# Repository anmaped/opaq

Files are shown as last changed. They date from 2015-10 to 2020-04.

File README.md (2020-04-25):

# Opaq - IoT aquarium and pond controllers for everyone
#### Release 1.0.7



Main screen |  Settings Screen | Wifi Settings | Graph
:-----------:|:----------------:|:------:|:-------:
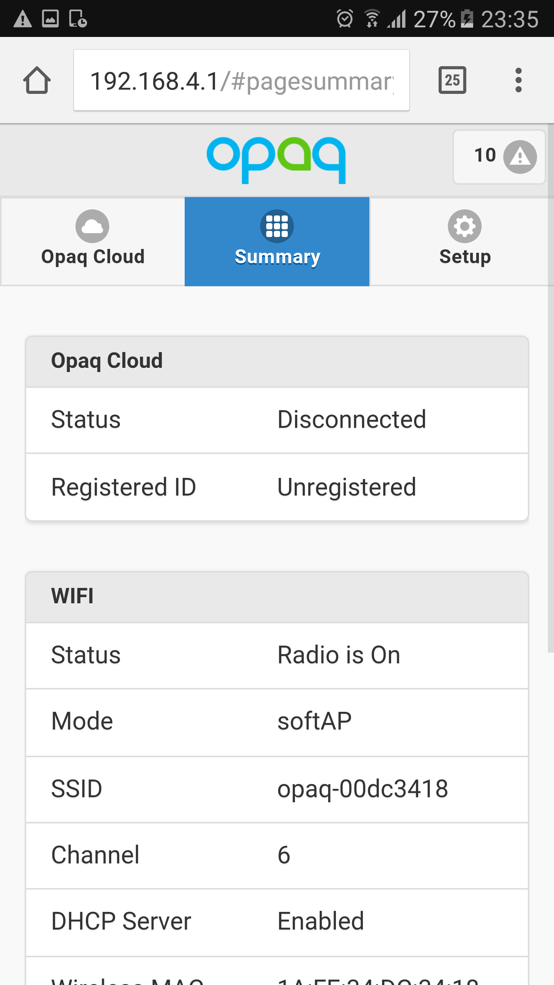
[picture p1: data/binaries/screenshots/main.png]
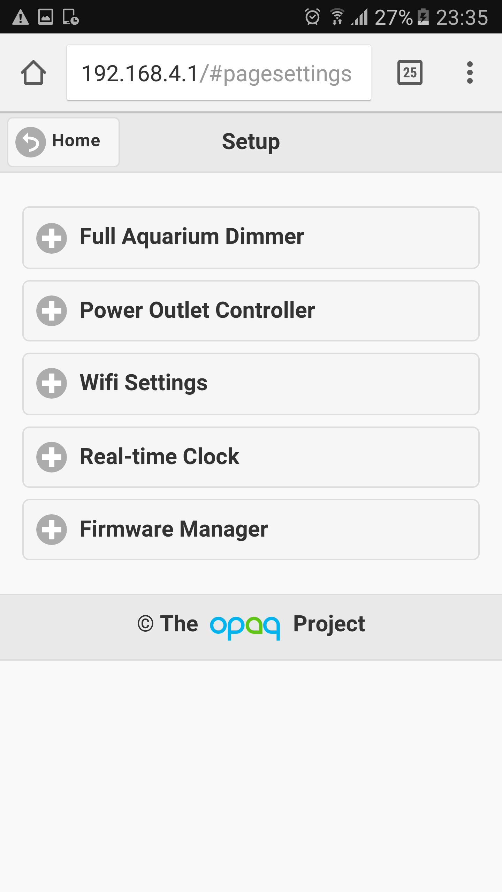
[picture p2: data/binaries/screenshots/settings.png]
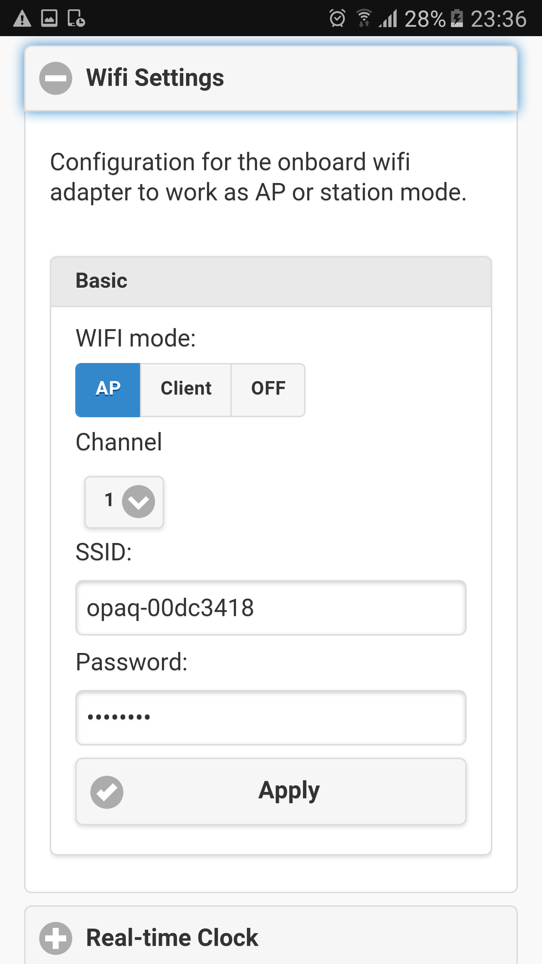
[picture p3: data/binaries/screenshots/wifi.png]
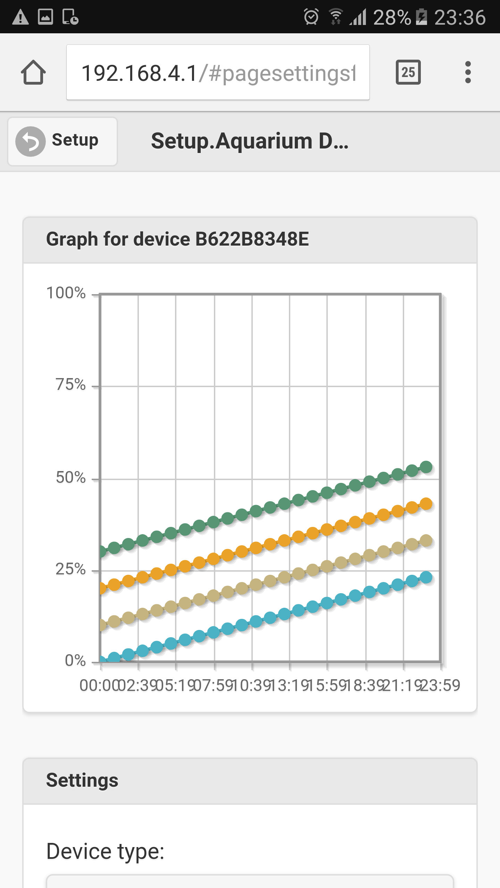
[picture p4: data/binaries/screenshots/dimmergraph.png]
 |   |   |  

Supported features:
- Browser-based graphical user interface to control light and power devices of aquarium and pond systems
- Customizable programming actions for nodes such as automation of CO2 injection and temperature management
- Node-based architecture (nodes are authentic, secured with SHA256 signatures)
- Energy cost management that instruct you how to avoid wasting energy

Opaq devices available:

Opaq c1 | Opaq n1 | Opaq n2 | Opaq n3
:------:|:---------:|:---------:|:---------:
the main controller device Opaq C1 Frame | the four channel dimmer device capable to connect with any led lamp (several settings available) Opaq n1 Frame | the power outlet controller node for 220v devices up to 1400w Opaq n2 Frame | battery powered wireless sensor node Opaq n3 Frame

Expected features:
- Support for sensor logging (temperature, humidity, light intensity, PH, Nitrates(NO3))
- Management of peristaltic pumps for automatic fertilization regimes for fresh and salt water aquariums
- Dedicated settings for aquarium and pond systems (pond systems can be controlled by Opaq C1 to automatically perform programmable water changes, and feed fishes; pumps are controlled by programmable actions based on the information provided by water level sensor nodes)
- Dedicated non-introsive water management system based on opaq n2 battery powered 'mope' for sumps and Koi ponds
- Embedded UI

Expected Hardware:
- Opaq N3 (the node for probing PH, light intensity and humidity)

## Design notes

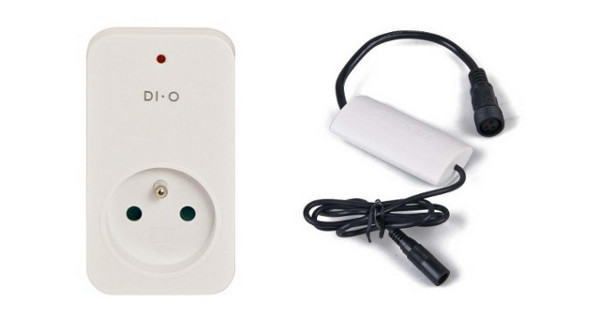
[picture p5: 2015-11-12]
tools/images/lp_sample.jpeg

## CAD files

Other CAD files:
hardware/opac_c1/v1.1/eagleUp/board.skp
hardware/opac_n1/v2.1/eagleUp/board.skp

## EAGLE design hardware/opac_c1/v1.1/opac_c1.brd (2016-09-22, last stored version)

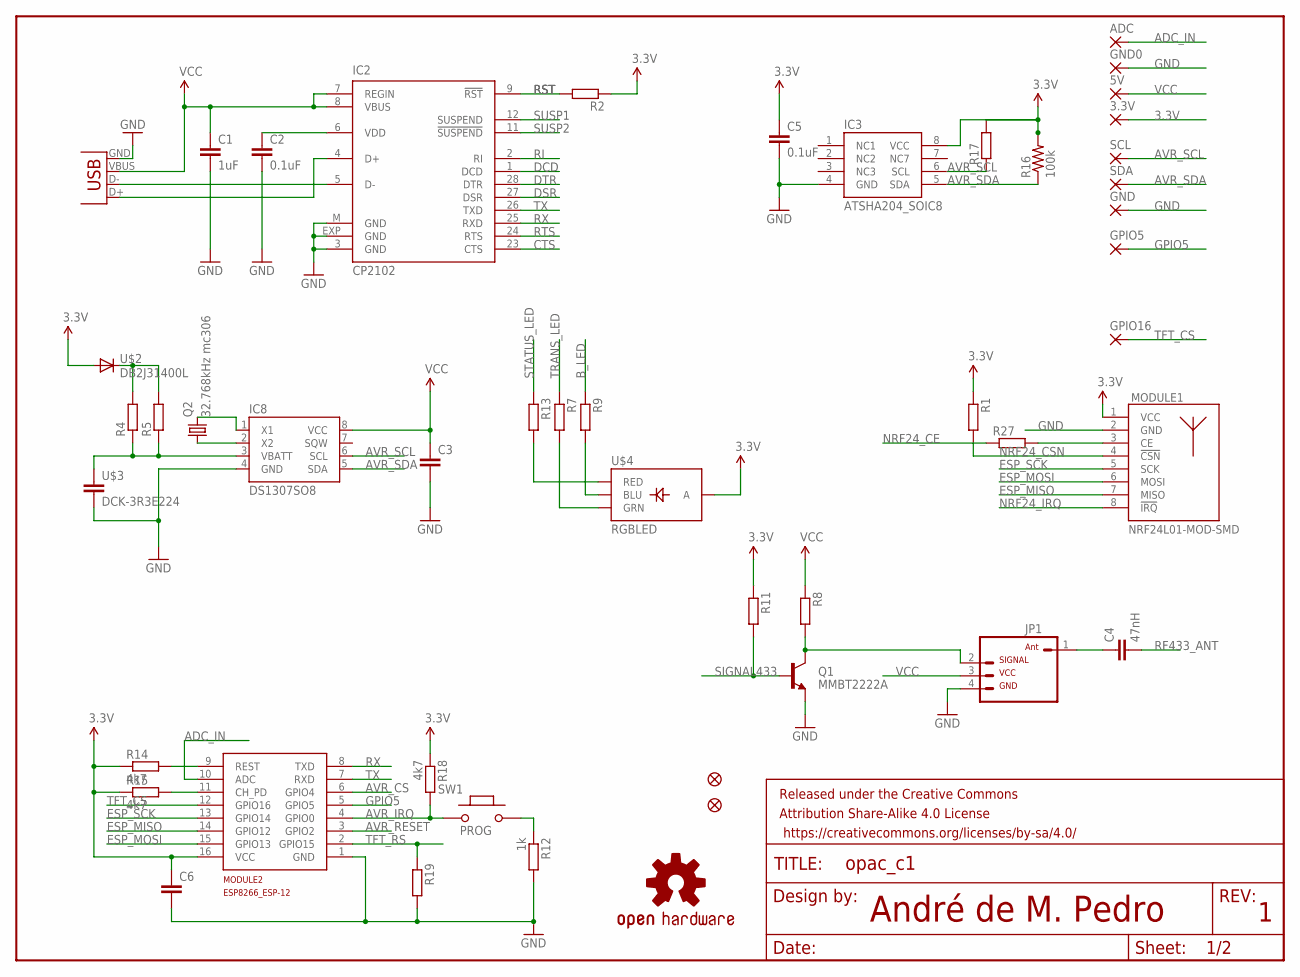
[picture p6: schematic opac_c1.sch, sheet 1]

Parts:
3.3V, 5V: SMD2; SMD1,27-2,54
ADC: SMD2; SMD1,27-2,54
C1: 1uF; 0603
C2: 0.1uF; 0603
C3, C6: C-EUC0805K; C0805K
C4: 47nH; C0603K
C5: 0.1uF; 0805
FRAME1: FRAME-LETTER; CREATIVE_COMMONS
GND, GND0: SMD2; SMD1,27-2,54
GPIO5, GPIO16: SMD2; SMD1,27-2,54
IC2: CP2102; MLP28
IC3: ATSHA204_SOIC8; SOIC8
IC8: DS1307SO8; SO08
JP1: RF433SMD; 1X04-SMD
JP2, JP3: FIDUCIAL1X2.5; FIDUCIAL-1X2.5
LOGO1: OSHW-LOGOL; OSHW-LOGO-L
MODULE1: NRF24L01-MOD-SMD; SMD8-MODULE
MODULE2: ESP8266_ESP-12; ESP8266-ESP12
Q1: MMBT2222A; SOT23-3
Q2: 32.768kHz mc306; MC-306
R1, R4, R5, R8, R11, R17, R19, R27: R-EU_R0805; 0805
R2, R7, R9, R13: R-EU_R0603; R0603
R12: 1k; 0805
R14, R15, R18: 4k7; 0805
R16: 100k; 0805
SCL: SMD2; SMD1,27-2,54
SDA: SMD2; SMD1,27-2,54
SW1: PROG; 157SW; PARTNO RS 682-1421
U$2: DB2J31400L; SMINI2-F5-B
U$3: DCK-3R3E224
U$4: RGBLED; RGBLED0603
USB1: USB-MICROB

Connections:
3.3V: 3.3V.1, C5.1, C6.1, IC3.8 (VCC), MODULE1.1 (VCC), MODULE2.16 (VCC), R1.1, R2.1, R11.1, R14.1, R15.1, R16.2, R17.2, R18.1, U$2.P$2 (A), U$4.P$3 (A); also elsewhere on the board
ADC_IN: ADC.1, MODULE2.10 (ADC)
AVR_CS: MODULE2.6 (GPIO4); also elsewhere on the board
AVR_IRQ: MODULE2.4 (GPIO0), R18.2, SW1.1; also elsewhere on the board
AVR_RESET: MODULE2.3 (GPIO2); also elsewhere on the board
AVR_SCL: IC3.6 (SCL), IC8.6 (SCL), R17.1, SCL.1; also elsewhere on the board
AVR_SDA: IC3.5 (SDA), IC8.5 (SDA), R16.1, SDA.1; also elsewhere on the board
B_LED: R9.1; also elsewhere on the board
CTS: IC2.23 (CTS)
DCD: IC2.1 (DCD)
DSR: IC2.27 (DSR)
DTR: IC2.28 (DTR)
ESP_MISO: MODULE1.7 (MISO), MODULE2.14 (GPIO12); also elsewhere on the board
ESP_MOSI: MODULE1.6 (MOSI), MODULE2.15 (GPIO13); also elsewhere on the board
ESP_SCK: MODULE1.5 (SCK), MODULE2.13 (GPIO14); also elsewhere on the board
GND: C1.2, C2.2, C3.2, C5.2, C6.2, GND.1, GND0.1, IC2.3 (GND), IC2.EXP (GND), IC2.M (GND), IC3.4 (GND), IC8.4 (GND), JP1.4 (2), MODULE1.2 (GND), MODULE2.1 (GND), Q1.2 (E), R12.2, R19.2, U$3.P$1 (2), USB1.GND; also elsewhere on the board
GPIO5: GPIO5.1, MODULE2.5 (GPIO5)
unnamed: IC8.3 (VBATT), R4.1, R5.1, U$3.P$2 (1)
unnamed: IC8.2 (X2), Q2.1
unnamed: R4.2, R5.2, U$2.P$1 (C)
unnamed: C2.1, IC2.6 (VDD)
unnamed: IC8.1 (X1), Q2.4 (2)
unnamed: R13.2, U$4.P$1 (RED)
unnamed: R12.1, SW1.2
unnamed: IC2.5 (D-), USB1.D-
unnamed: R7.2, U$4.P$2 (GRN)
unnamed: IC2.4 (D+), USB1.D+
unnamed: JP1.2 (3), Q1.3 (C), R8.2
unnamed: R9.2, U$4.P$4 (BLU)
unnamed: MODULE1.3 (CE), R27.2
unnamed: C4.1, JP1.1 (4)
unnamed: MODULE2.9 (REST), R14.2
unnamed: MODULE2.11 (CH_PD), R15.2
NRF24_CE: R27.1; also elsewhere on the board
NRF24_CSN: MODULE1.4 (!CSN), R1.2; also elsewhere on the board
NRF24_IRQ: MODULE1.8 (!IRQ); also elsewhere on the board
RF433_ANT: C4.2
RI: IC2.2 (RI)
RST: IC2.9 (!RST), R2.2
RTS: IC2.24 (RTS)
RX: IC2.25 (RXD), MODULE2.8 (TXD)
SIGNAL433: Q1.1 (B), R11.2; also elsewhere on the board
STATUS_LED: R13.1; also elsewhere on the board
SUSP1: IC2.12 (SUSPEND)
SUSP2: IC2.11 (!SUSPEND)
TFT_CS: GPIO16.1, MODULE2.12 (GPIO16); also elsewhere on the board
TFT_RS: MODULE2.2 (GPIO15), R19.1; also elsewhere on the board
TRANS_LED: R7.1; also elsewhere on the board
TX: IC2.26 (TXD), MODULE2.7 (RXD)
VCC: 5V.1, C1.1, C3.1, IC2.7 (REGIN), IC2.8 (VBUS), IC8.8 (VCC), JP1.3 (1), R8.1, USB1.VBUS; also elsewhere on the board

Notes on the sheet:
André de M. Pedro

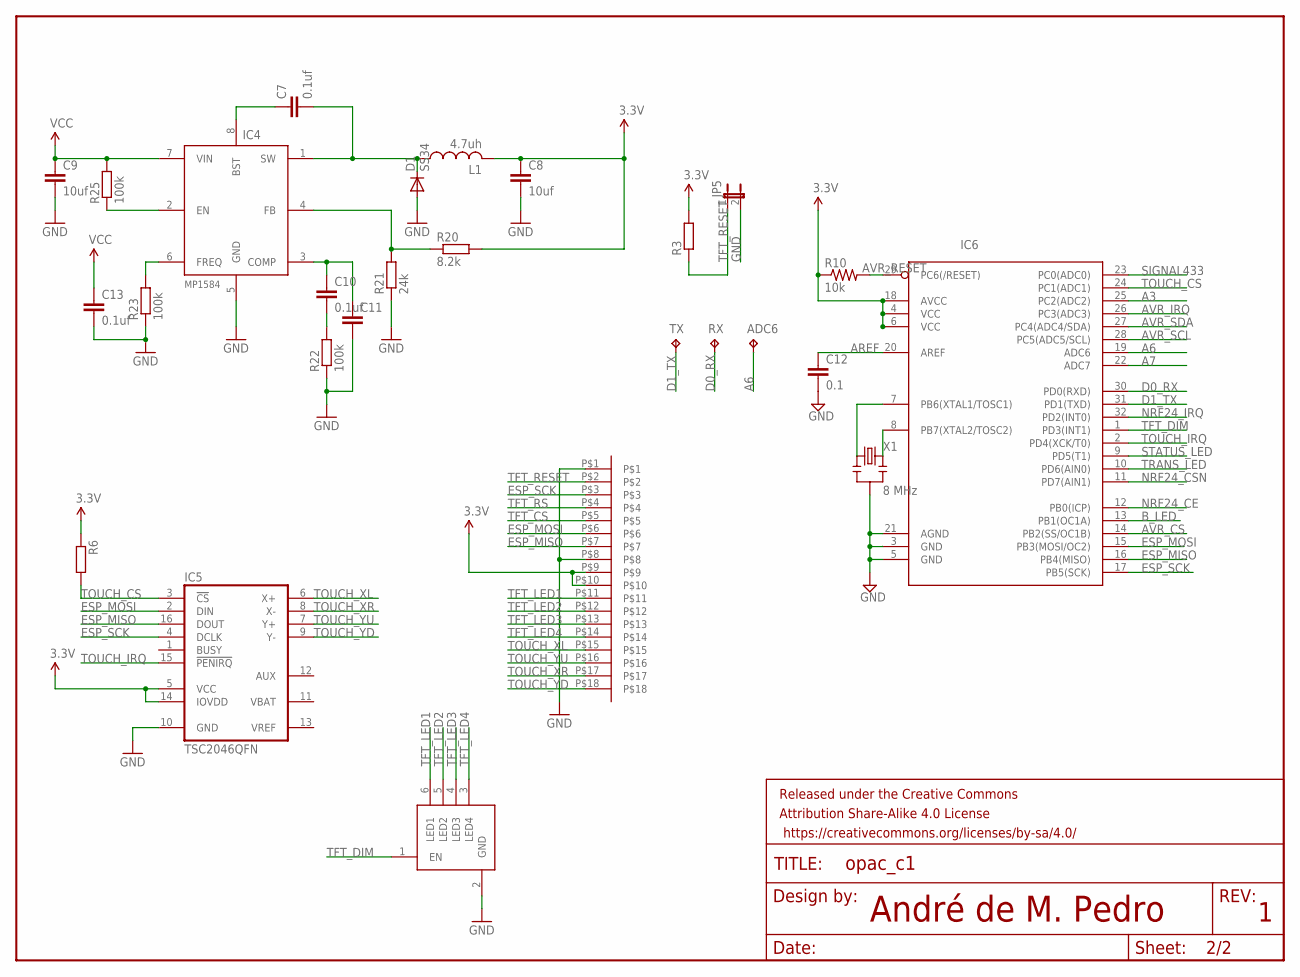
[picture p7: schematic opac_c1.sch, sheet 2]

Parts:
ADC6: TPTP09R; TP09R
C7, C10, C13: 0.1uf; C0603
C8, C9: 10uf; C3216
C11: C-EUC0603; C0603
C12: 0.1; 0805
D1: SS34; SMA-DIODE
FRAME2: FRAME-LETTER; CREATIVE_COMMONS
IC4: MP1584; SO08-EPAD
IC5: TSC2046QFN; QFN16-4X4
IC6: ATMega-328; MLF32
IC7: RT9300; SOT23-6
JP5: JUMPER-2SMD-NO; SJ_2S-NO
L1: 4.7uh; 2525
R3: R-EU_R0402; R0402
R6: R-EU_R0805; 0805
R10: 10k; 0603-RES
R20: 8.2k; R0603
R21: 24k; R0603
R22, R23, R25: 100k; R0603
RX: TPTP10SQ; TP10SQ
TX: TPTP10SQ; TP10SQ
U$1: CONNECTOR8P0.8; CONNECTOR18P0.8
X1: 8 MHz; RESONATOR-SMD

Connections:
3.3V: C8.1, IC5.5 (VCC), IC5.14 (IOVDD), IC6.4 (VCC), IC6.6 (VCC), IC6.18 (AVCC), L1.P$1, R3.2, R6.1, R10.1, R20.2, U$1.P$9, U$1.P$10; also elsewhere on the board
A3: IC6.25 (PC2(ADC2))
A6: ADC6.TP, IC6.19 (ADC6)
A7: IC6.22 (ADC7)
AREF: C12.1, IC6.20 (AREF)
AVR_CS: IC6.14 (PB2(SS/OC1B)); also elsewhere on the board
AVR_IRQ: IC6.26 (PC3(ADC3)); also elsewhere on the board
AVR_RESET: IC6.29 (PC6(/RESET)), R10.2; also elsewhere on the board
AVR_SCL: IC6.28 (PC5(ADC5/SCL)); also elsewhere on the board
AVR_SDA: IC6.27 (PC4(ADC4/SDA)); also elsewhere on the board
B_LED: IC6.13 (PB1(OC1A)); also elsewhere on the board
D0_RX: IC6.30 (PD0(RXD)), RX.TP
D1_TX: IC6.31 (PD1(TXD)), TX.TP
ESP_MISO: IC5.16 (DOUT), IC6.16 (PB4(MISO)), U$1.P$7; also elsewhere on the board
ESP_MOSI: IC5.2 (DIN), IC6.15 (PB3(MOSI/OC2)), U$1.P$6; also elsewhere on the board
ESP_SCK: IC5.4 (DCLK), IC6.17 (PB5(SCK)), U$1.P$3; also elsewhere on the board
GND: C8.2, C9.2, C11.2, C12.2, C13.2, D1.A, IC4.5 (GND), IC5.10 (GND), IC6.3 (GND), IC6.5 (GND), IC6.21 (AGND), IC7.2 (GND), JP5.2, R21.1, R22.1, R23.1, U$1.P$1, U$1.P$8, X1.2; also elsewhere on the board
unnamed: IC6.7 (PB6(XTAL1/TOSC1)), X1.1
unnamed: IC6.8 (PB7(XTAL2/TOSC2)), X1.3
unnamed: C7.2, D1.C, IC4.1 (SW), L1.P$2
unnamed: C7.1, IC4.8 (BST)
unnamed: IC4.4 (FB), R20.1, R21.2
unnamed: IC4.2 (EN), R25.1
unnamed: IC4.6 (FREQ), R23.2
unnamed: C10.1, C11.1, IC4.3 (COMP)
unnamed: C10.2, R22.2
NRF24_CE: IC6.12 (PB0(ICP)); also elsewhere on the board
NRF24_CSN: IC6.11 (PD7(AIN1)); also elsewhere on the board
NRF24_IRQ: IC6.32 (PD2(INT0)); also elsewhere on the board
SIGNAL433: IC6.23 (PC0(ADC0)); also elsewhere on the board
STATUS_LED: IC6.9 (PD5(T1)); also elsewhere on the board
TFT_CS: U$1.P$5; also elsewhere on the board
TFT_DIM: IC6.1 (PD3(INT1)), IC7.1 (EN)
TFT_LED1: IC7.6 (LED1), U$1.P$11
TFT_LED2: IC7.5 (LED2), U$1.P$12
TFT_LED3: IC7.4 (LED3), U$1.P$13
TFT_LED4: IC7.3 (LED4), U$1.P$14
TFT_RESET: JP5.1, R3.1, U$1.P$2
TFT_RS: U$1.P$4; also elsewhere on the board
TOUCH_CS: IC5.3 (!CS), IC6.24 (PC1(ADC1)), R6.2
TOUCH_IRQ: IC5.15 (!PENIRQ), IC6.2 (PD4(XCK/T0))
TOUCH_XL: IC5.6 (X+), U$1.P$15
TOUCH_XR: IC5.8 (X-), U$1.P$17
TOUCH_YD: IC5.9 (Y-), U$1.P$18
TOUCH_YU: IC5.7 (Y+), U$1.P$16
TRANS_LED: IC6.10 (PD6(AIN0)); also elsewhere on the board
VCC: C9.1, C13.1, IC4.7 (VIN), R25.2; also elsewhere on the board

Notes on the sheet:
André de M. Pedro

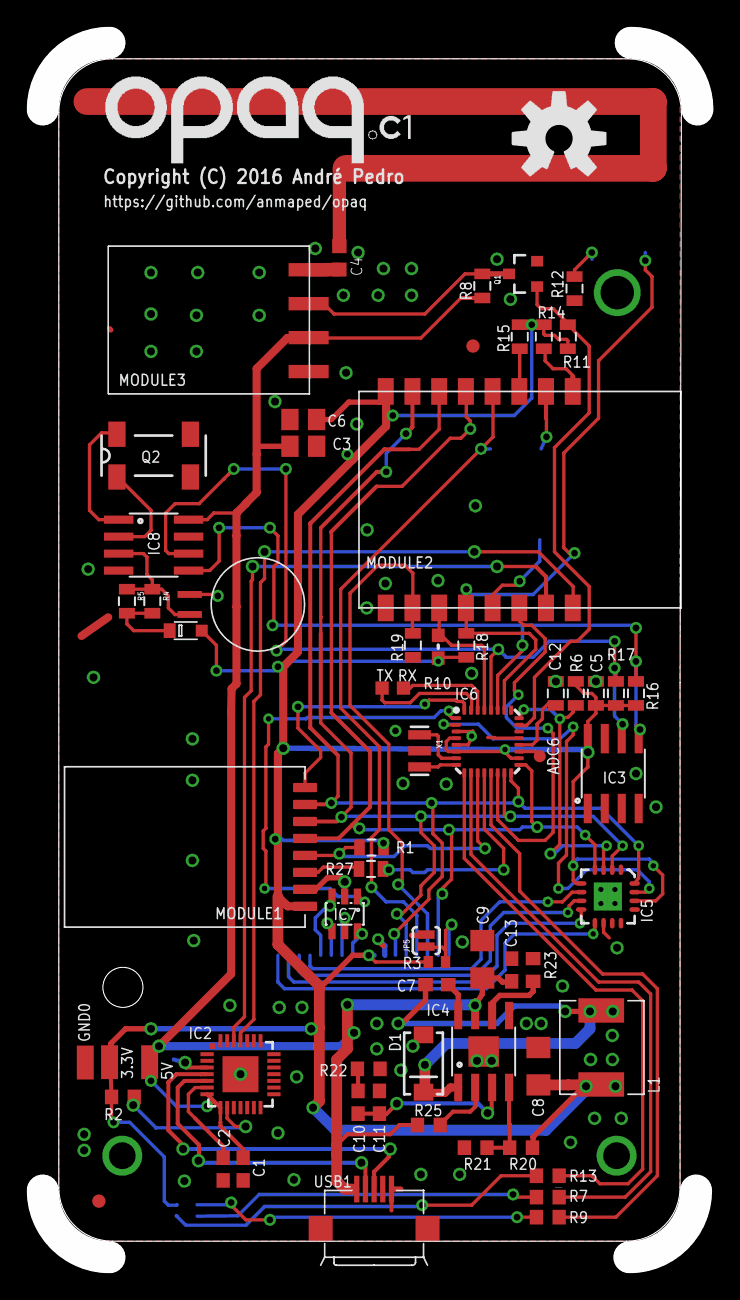
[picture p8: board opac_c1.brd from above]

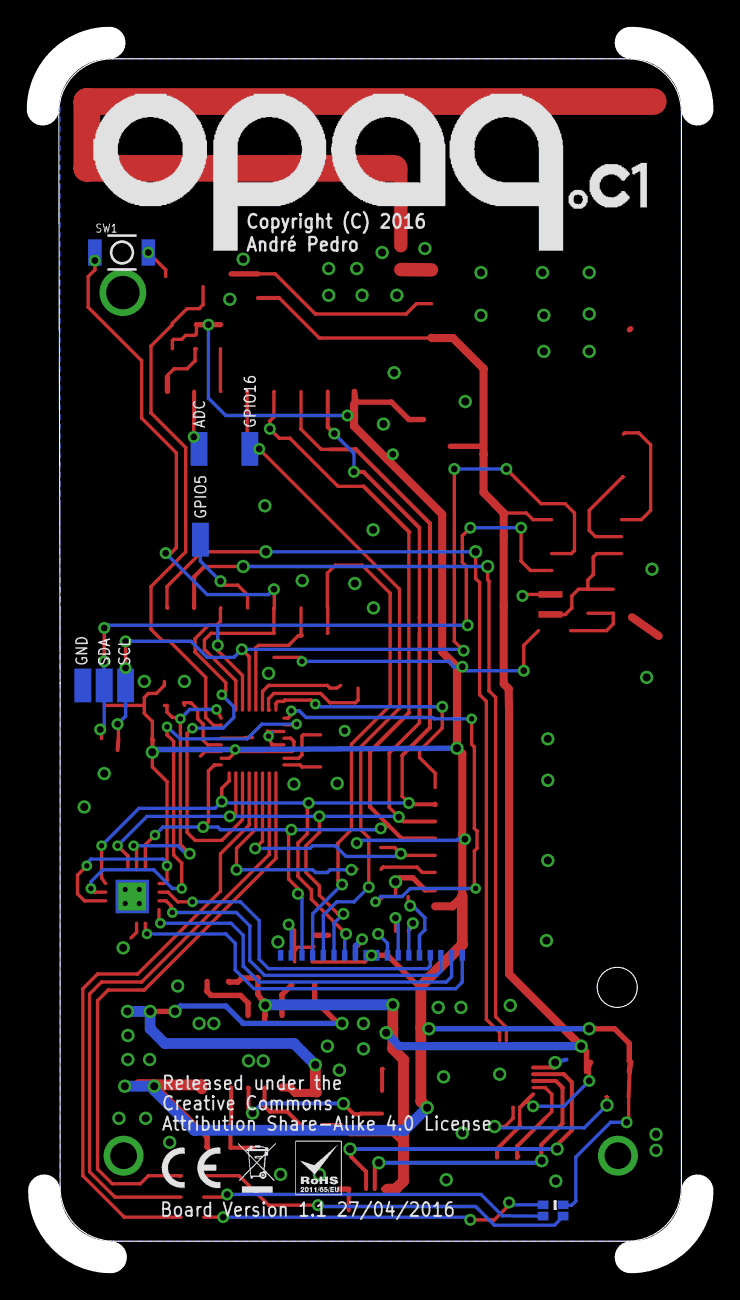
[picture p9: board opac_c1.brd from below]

Board: 2 copper layers, 49.0 x 90.9 mm, 77 parts (9 on the bottom side), 66 nets.

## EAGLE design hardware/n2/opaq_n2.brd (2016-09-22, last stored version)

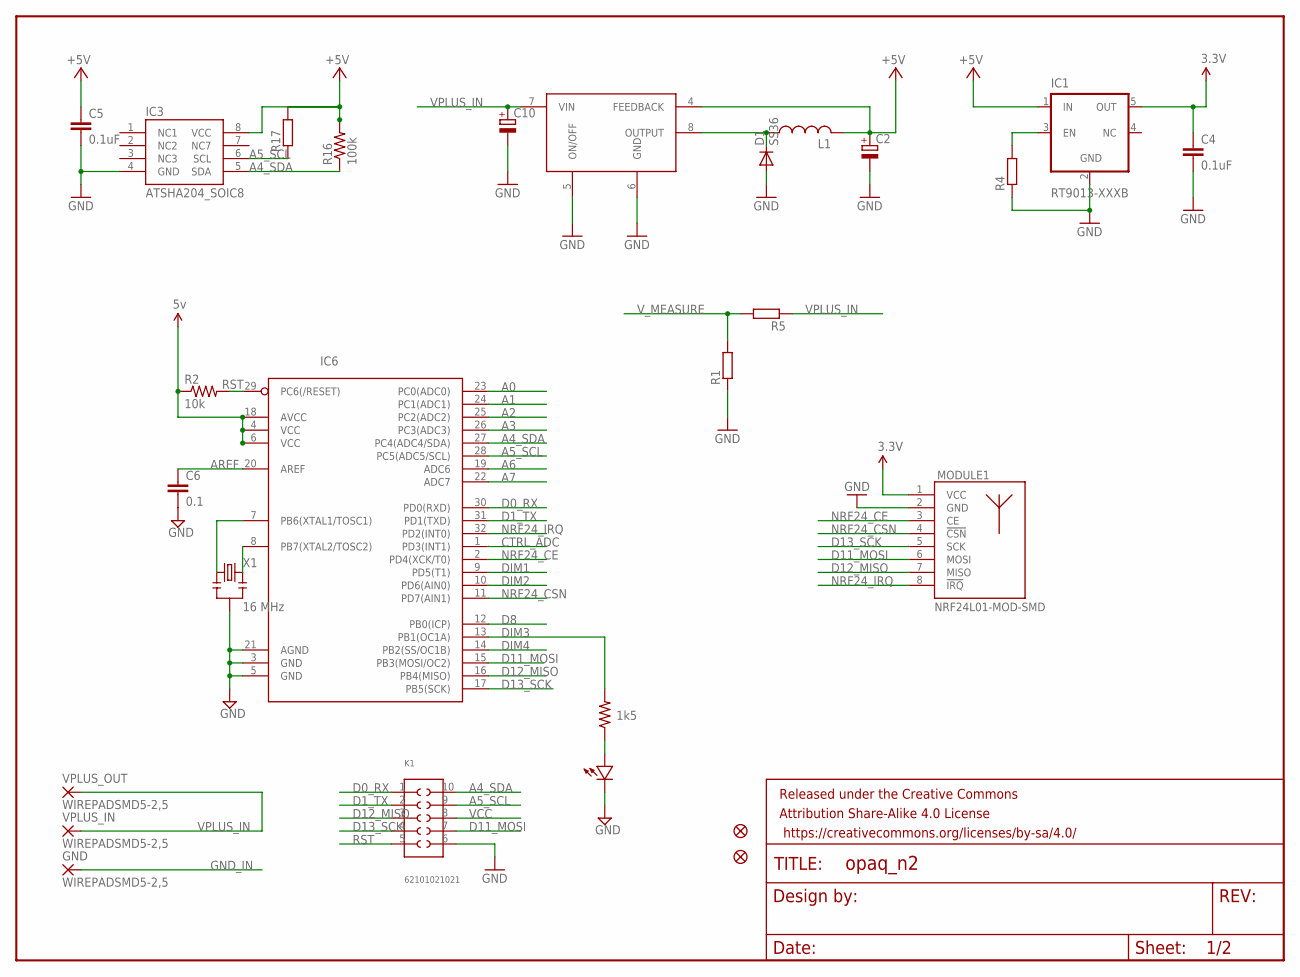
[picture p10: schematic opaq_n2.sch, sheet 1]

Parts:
C2: CPOL-EUC/6032-28R; C/6032-28R
C4, C5: 0.1uF; 0805
C6: 0.1; 0603-CAP
C10: CPOL-EUD/7343-31R; D/7343-31R
D1: SS36; SMA-DIODE
DIM: LED0603; 0603-LED
FRAME1: FRAME-LETTER; CREATIVE_COMMONS
GND: WIREPADSMD5-2,5; 5-2,5
IC1: RT9013-XXXB; SOT23-5
IC3: ATSHA204_SOIC8; SOIC8
IC6: ATMega-328; MLF32
IC8: LM2594HV; SO08
JP1, JP2: FIDUCIAL1X2.5; FIDUCIAL-1X2.5
K1: 62101021021
L1: NR6045; 2525
MODULE1: NRF24L01-MOD-SMD; SMD8-MODULE
R1, R4, R5, R17: R-EU_R0805; 0805
R2: 10k; 0603-RES
R3: 1k5; 0603-RES
R16: 100k; 0805
VPLUS_IN: WIREPADSMD5-2,5; 5-2,5
VPLUS_OUT: WIREPADSMD5-2,5; 5-2,5
X1: 16 MHz; RESONATOR-SMD

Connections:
3.3V: C4.1, IC1.5 (OUT), MODULE1.1 (VCC)
+5V: C2.+, C5.1, IC1.1 (IN), IC3.8 (VCC), IC8.4 (FEEDBACK), L1.P$1, R16.2, R17.2; also elsewhere on the board
A0: IC6.23 (PC0(ADC0))
A1: IC6.24 (PC1(ADC1))
A2: IC6.25 (PC2(ADC2))
A3: IC6.26 (PC3(ADC3))
A4_SDA: IC3.5 (SDA), IC6.27 (PC4(ADC4/SDA)), K1.10, R16.1; also elsewhere on the board
A5_SCL: IC3.6 (SCL), IC6.28 (PC5(ADC5/SCL)), K1.9, R17.1; also elsewhere on the board
A6: IC6.19 (ADC6)
A7: IC6.22 (ADC7)
AREF: C6.1, IC6.20 (AREF)
CTRL_ADC: IC6.1 (PD3(INT1)); also elsewhere on the board
D0_RX: IC6.30 (PD0(RXD)), K1.1
D1_TX: IC6.31 (PD1(TXD)), K1.2
D8: IC6.12 (PB0(ICP)); also elsewhere on the board
D11_MOSI: IC6.15 (PB3(MOSI/OC2)), K1.7, MODULE1.6 (MOSI); also elsewhere on the board
D12_MISO: IC6.16 (PB4(MISO)), K1.3, MODULE1.7 (MISO); also elsewhere on the board
D13_SCK: IC6.17 (PB5(SCK)), K1.4, MODULE1.5 (SCK); also elsewhere on the board
DIM1: IC6.9 (PD5(T1))
DIM2: IC6.10 (PD6(AIN0))
DIM3: IC6.13 (PB1(OC1A)), R3.2
DIM4: IC6.14 (PB2(SS/OC1B))
GND: C2.-, C4.2, C5.2, C6.2, C10.-, D1.A, DIM.MINUS, IC1.2 (GND), IC3.4 (GND), IC6.3 (GND), IC6.5 (GND), IC6.21 (AGND), IC8.5 (ON/OFF), IC8.6 (GND), K1.6, MODULE1.2 (GND), R1.1, R4.1, X1.2; also elsewhere on the board
GND_IN: GND.1; also elsewhere on the board
unnamed: IC6.7 (PB6(XTAL1/TOSC1)), X1.1
unnamed: DIM.PLUS, R3.1
unnamed: IC1.3 (EN), R4.2
unnamed: D1.C, IC8.8 (OUTPUT), L1.P$2
unnamed: IC6.8 (PB7(XTAL2/TOSC2)), X1.3
NRF24_CE: IC6.2 (PD4(XCK/T0)), MODULE1.3 (CE)
NRF24_CSN: IC6.11 (PD7(AIN1)), MODULE1.4 (!CSN)
NRF24_IRQ: IC6.32 (PD2(INT0)), MODULE1.8 (!IRQ)
RST: IC6.29 (PC6(/RESET)), K1.5, R2.2
VCC: IC6.4 (VCC), IC6.6 (VCC), IC6.18 (AVCC), K1.8, R2.1; also elsewhere on the board
VPLUS_IN: C10.+, IC8.7 (VIN), R5.1, VPLUS_IN.1, VPLUS_OUT.1
V_MEASURE: R1.2, R5.2; also elsewhere on the board

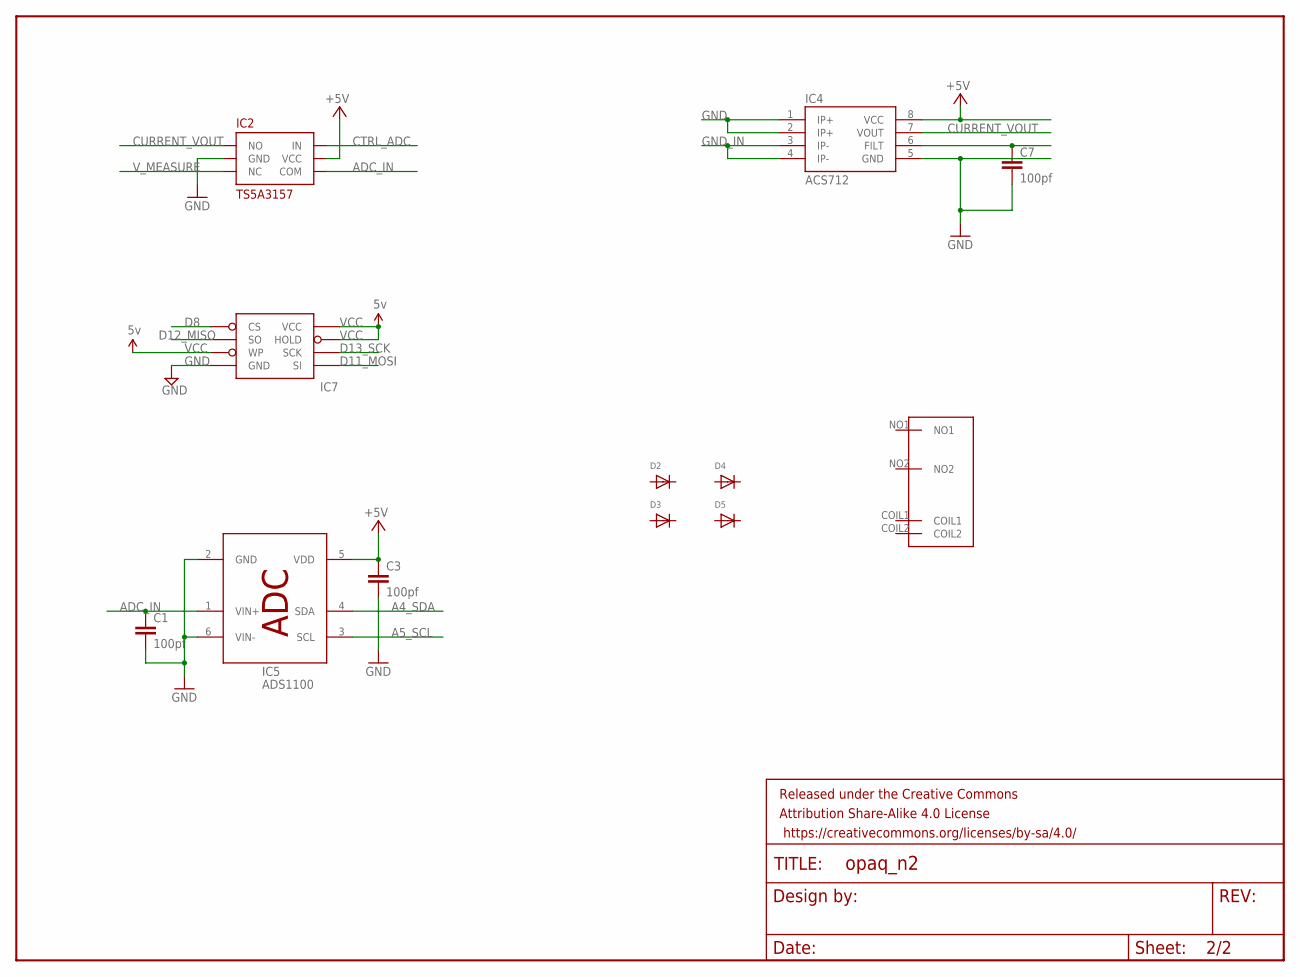
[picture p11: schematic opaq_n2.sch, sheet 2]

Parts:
C1, C3, C7: 100pf; 0402-CAP
D2, D3, D4, D5: DIODESMA; SMADIODE
FRAME2: FRAME-LETTERNO_PACKAGE; DUMMY
IC2: TS5A3157; SOT23-6
IC4: ACS712; SO08
IC5: ADS1100; SOT23-6
IC7: AT25F512BWIDE_5.3MM; SO08WIDE
U$1: OMRON_G6M-1A

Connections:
+5V: C3.1, IC2.5 (VCC), IC4.8 (VCC), IC5.5 (VDD); also elsewhere on the board
A4_SDA: IC5.4 (SDA); also elsewhere on the board
A5_SCL: IC5.3 (SCL); also elsewhere on the board
ADC_IN: C1.1, IC2.4 (COM), IC5.1 (VIN+)
CTRL_ADC: IC2.6 (IN); also elsewhere on the board
CURRENT_VOUT: IC2.1 (NO), IC4.7 (VOUT)
D8: IC7.1 (CS); also elsewhere on the board
D11_MOSI: IC7.5 (SI); also elsewhere on the board
D12_MISO: IC7.2 (SO); also elsewhere on the board
D13_SCK: IC7.6 (SCK); also elsewhere on the board
FILT: C7.1, IC4.6 (FILT)
GND: C1.2, C3.2, C7.2, IC2.2 (GND), IC4.1 (IP+), IC4.2 (IP+), IC4.5 (GND), IC5.2 (GND), IC5.6 (VIN-), IC7.4 (GND); also elsewhere on the board
GND_IN: IC4.3 (IP-), IC4.4 (IP-); also elsewhere on the board
VCC: IC7.3 (WP), IC7.7 (HOLD), IC7.8 (VCC); also elsewhere on the board
V_MEASURE: IC2.3 (NC); also elsewhere on the board

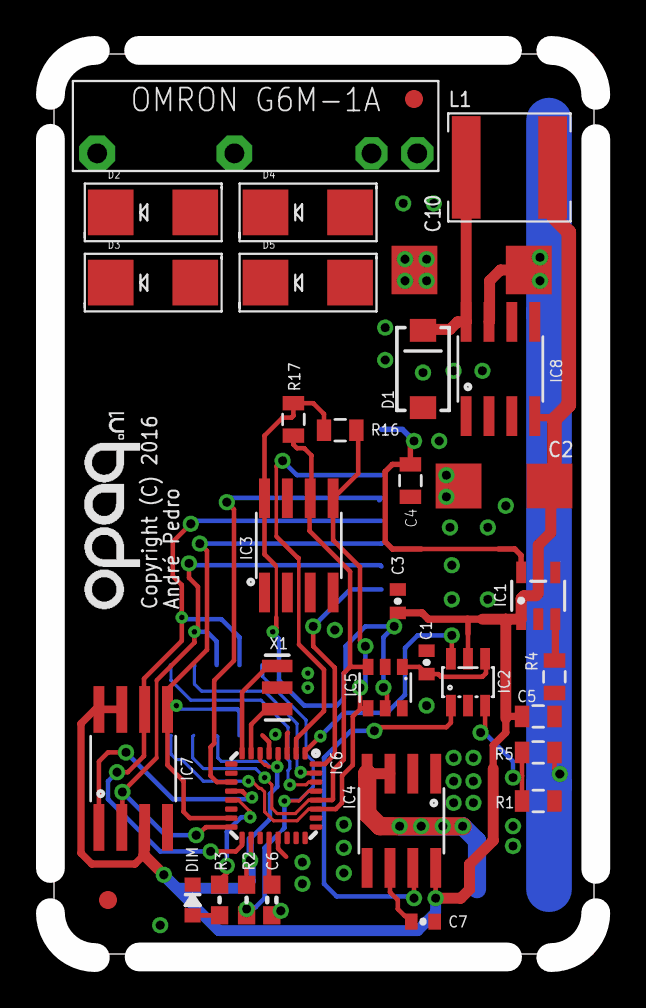
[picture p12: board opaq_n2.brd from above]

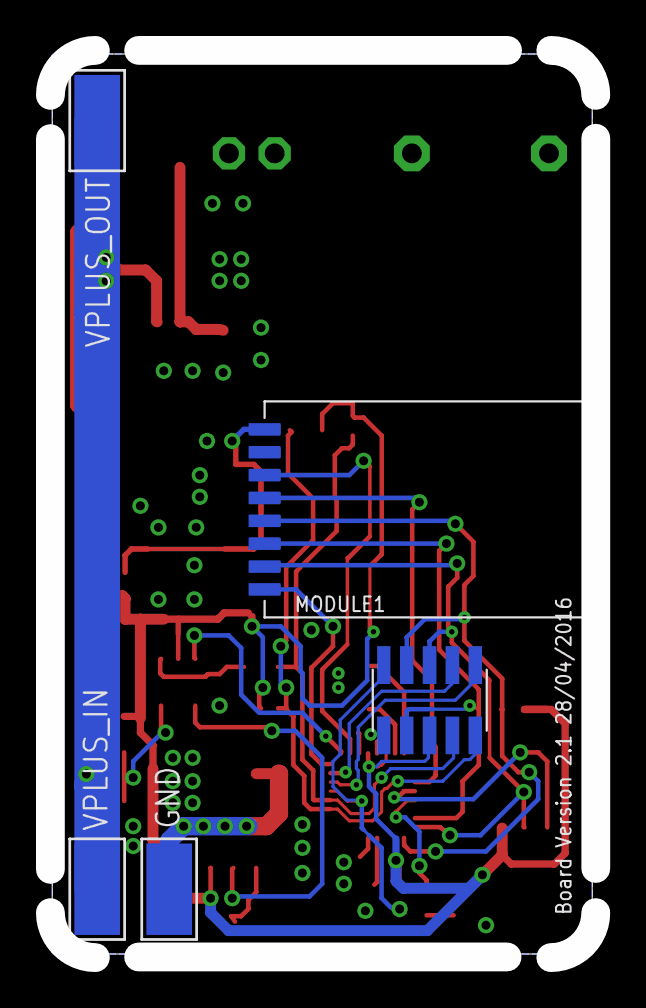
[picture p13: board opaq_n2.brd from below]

Board: 2 copper layers, 30.0 x 50.0 mm, 41 parts (5 on the bottom side), 30 nets.

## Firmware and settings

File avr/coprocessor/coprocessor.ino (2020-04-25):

#include "atsha204.h"
#include "ds1307.h"
#include "protocol.h"
#include "rf433.h"
#include "version.h"

#include <RtcDS1307.h>
#include <SPI.h>
#include <Scheduler.h>
#include <Wire.h>

#include <SHA204.h>
#include <SHA204Definitions.h>
#include <SHA204I2C.h>

// pinout
#define PIN_NRF24_CSN 7
#define PIN_NRF24_CE 8
#define PIN_TOUCH_CS A1

#define RED_LED 5
#define GREEN_LED 6
#define BLUE_LED 9

volatile byte command = 0;
volatile bool comunicating = 0;
volatile byte count = 0;


// the setup function runs once when you press reset or power the board
void setup() {

  delay(100);

  Serial.begin(9600);

  pinMode(11, INPUT);
  pinMode(12, OUTPUT);
  pinMode(13, INPUT);
  pinMode(10, INPUT);

  // turn on SPI in slave mode
  SPCR |= _BV(SPE);

  // turn on interrupts
  SPCR |= _BV(SPIE);

  /**
   * Pin Change Interrupt enable on PCINT0 (PB0)
   */
  PCICR |= _BV(PCIE0);
  PCMSK0 = 0;
  PCMSK0 |= _BV(PCINT2);

  // Turn interrupts on.
  sei();

  // initialize digital pin 13 as an output.
  pinMode(5, OUTPUT); // green
  pinMode(6, OUTPUT); // red
  pinMode(9, OUTPUT); // blue

  pinMode(PIN_NRF24_CSN, OUTPUT); // pin NRF24_CSN
  pinMode(PIN_NRF24_CE, OUTPUT);  // pin NRF24_CE
  pinMode(PIN_TOUCH_CS, OUTPUT);  // pin TOUCH_CS
  digitalWrite(PIN_NRF24_CSN, HIGH);
  digitalWrite(PIN_NRF24_CE, HIGH);
  digitalWrite(PIN_TOUCH_CS, HIGH);

  pinMode(3, OUTPUT);
  analogWrite(3, 255);

  // real-time clock
  rtc.Begin();
  // rtc.SetDateTime(RtcDateTime(2016,5,25,5,34,0));
  rtc.SetIsRunning(true);

  sha204dev.init();
  wakeupExample();       // dummy
  serialNumberExample(); // dummy

  // RF433 setup
  Rf433_transmitter.set_pin(A0);
  Rf433_transmitter.set_encoding(Rf433_transmitter.CHANON_DIO_DEVICE);

  Scheduler.start(setup_status, loop_status);
  Scheduler.start(setup_com, loop_com);
  Scheduler.start(setup_warning, loop_warning);
}

void setup_status() { pinMode(GREEN_LED, OUTPUT); }

void loop_status() {
  if (!comunicating) {
    blink(GREEN_LED, 500);
  } else {
    digitalWrite(GREEN_LED, LOW);
    delay(1000);
  }
}

void setup_com() { pinMode(BLUE_LED, OUTPUT); }

void loop_com() {
  digitalWrite(BLUE_LED, LOW);
  delay(100);
  digitalWrite(BLUE_LED, HIGH);
  delay(500);
  digitalWrite(BLUE_LED, LOW);
  delay(100);
  digitalWrite(BLUE_LED, HIGH);
  delay(2000);
}

void setup_warning() { pinMode(RED_LED, OUTPUT); }

void loop_warning() {
  if (true) {
    digitalWrite(RED_LED, HIGH);
    delay(1000);
  } else {
    blink(RED_LED, 500);
  }
}

void blink(int pin, unsigned int ms) {
  digitalWrite(pin, HIGH);
  delay(ms);
  digitalWrite(pin, LOW);
  delay(ms);
}

ISR(PCINT0_vect) {
  if (!(PINB & B00000100)) {
    PORTD |= B10000000;
    PORTC |= B00000010;
  } else {
    command = 0;
  }
}

// SPI interrupt routine
ISR(SPI_STC_vect) {
  byte data = SPDR;

  switch (command) {
  // no command? then this is the command
  case 0:
    SPDR = 1;
    command = data;
    count = 0;
    break;

  case ID_DS1307_GETDATA:

    if (count < sizeof(RtcDateTime))
      SPDR = ds1307(count);

    count++;
    comunicating = true;
    break;

  case ID_DS1307_SETDATA:

    if (count < sizeof(RtcDateTime)) {
      setDs1307(data, count);

      if (count == sizeof(RtcDateTime) - 1) {
        // update clock
        setClockActive = true;
      }
    }

    count++;
    break;

  case ID_NRF24_CSN:

    if (count == 0) {
      if (data == 0x01) {
        // digitalWrite(PIN_NRF24_CSN, HIGH);
        PORTD |= B10000000;
      } else {
        // digitalWrite(PIN_NRF24_CSN, LOW);
        PORTD &= B01111111;
      }
    }

    command = 0;
    break;

  case ID_NRF24_CE:

    if (data == HIGH) {
      digitalWrite(PIN_NRF24_CE, HIGH);
    } else {
      digitalWrite(PIN_NRF24_CE, LOW);
    }

    command = 0;
    break;

  case ID_ATSHA402:

    SPDR = serialNumber[count];

    count++;
    break;

  case ID_TSC2046_CSN:

    if (data == HIGH) {
      // digitalWrite(PIN_TOUCH_CS, HIGH);
      PORTC |= B00000010;
    } else {
      // digitalWrite(PIN_TOUCH_CS, LOW);
      PORTC &= B11111101;
    }

    command = 0;
    break;

  case ID_RF433_STREAM:

    // byte data = SPDR;
    // enqueue stream
    enqueue_stream(data, count);
    SPDR = data;

    count++;
    break;

  case ID_DIM_TFT:

    analogWrite(3, data);
    break;

  case ID_STATUS:
    
    byte *statusbitvector = (byte *)&st;
    SPDR = statusbitvector[count];

    count++;
    break;

  } // end of switch

} // end of interrupt service routine (ISR) SPI_STC_vect

void loop() {

  delay(10);

  if (setClockActive) {
    setClockActive = false;
    rtc.SetDateTime(clock);
  } else {
    clock = rtc.GetDateTime();
  }

  rf433();
}

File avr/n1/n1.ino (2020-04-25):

#include <Wire.h>
#include <OneWire.h>
#include <DallasTemperature.h>

#include <SPIFlash.h>
#include <Scheduler.h>

#include "nRF24L01.h"
#include "RF24.h"
#include "printf.h"
#include "RF24Network.h"
#include "RF24Mesh.h"

#include <SHA204.h>
#include <SHA204Definitions.h>
#include "SHA204ReturnCodes.h"
#include <SHA204I2C.h>

// ADS1100 I2C address is 0x48(72)
#define Addr 0x48

#define FLASH_SS 8
#define SPDT_SWITCH 3

RF24 radio(4,7);
RF24Network network(radio);
RF24Mesh mesh(radio, network);

SPIFlash flash(FLASH_SS, 0x1F65);

SHA204I2C sha204dev(0x64);

#define ONE_WIRE_BUS 18
OneWire oneWire(ONE_WIRE_BUS);
DallasTemperature sensors(&oneWire);

float temp;

void setup() {
  
  Serial.begin(115200);

  pinMode(SPDT_SWITCH, OUTPUT);
  pinMode(4,OUTPUT);
  
  pinMode(8,OUTPUT);
  pinMode(9,OUTPUT);
  pinMode(ONE_WIRE_BUS, OUTPUT);

  digitalWrite(4,LOW);

  digitalWrite(SPDT_SWITCH, LOW);
  digitalWrite(8,HIGH);
  digitalWrite(9,HIGH);
  digitalWrite(ONE_WIRE_BUS, LOW);

  Scheduler.begin(256);

  // to give oportunity to i2c comunication
  oneWire.skip();

  // NRF24 initialization
  printf_begin();
  mesh.setNodeID(0x02);
  // Connect to the mesh
  Serial.println(F("Connecting to the mesh..."));
  mesh.begin(MESH_DEFAULT_CHANNEL,RF24_250KBPS);
  
  radio.printDetails();

  // External Flash initialization
  if (flash.initialize())
  {
    Serial.println("Flash initialized.");
  }
  else
  {
    Serial.println("Flash FAIL!");
  }

  Serial.print("DeviceID: ");
  Serial.println(flash.readDeviceId(), HEX);

/*
  Serial.print("Erasing Flash chip ... ");
  flash.chipErase();
  while(flash.busy());
  Serial.println("DONE");

  for(int i=0; i < 100; i++)
  {
    flash.writeByte(i, 0x35+i);
  }
*/

  // read test
  /*for(int i=0; i < 100; i++)
  {
    Serial.print(flash.readByte(i), HEX);
    Serial.print(" ");
  }
  */

  delay(1000);

  digitalWrite(18,LOW);
  delay(1000);
  
  // crypto chip
  Wire.begin();
  //Wire.setClock(400000L);
  //Wire.setClock(100000L);
  //sha204dev.init();
  
  auto wakeupExample = []()
  {
    uint8_t response[SHA204_RSP_SIZE_MIN];
    byte returnValue;
    
    returnValue = sha204dev.resync(4, &response[0]);
    for (int i=0; i<SHA204_RSP_SIZE_MIN; i++) {
      Serial.print(response[i], HEX);
      Serial.print(" ");
    }
    Serial.println();
  };

  auto serialNumberExample = []()
  {
    uint8_t serialNumber[9];
    byte returnValue;
    
    returnValue = sha204dev.serialNumber(&serialNumber[0]);
    for (int i=0; i<9; i++) {
      Serial.print(serialNumber[i], HEX);
      Serial.print(" ");
    }
    Serial.println();
   
    Serial.println("-------"); 
    
    return returnValue;
  };
  
  //wakeupExample(); // dummy
 // for(int i=0; i<100; i++)
  {
    //delay(1000);
    //for(int i=0; i<5; i++)
  //serialNumberExample(); // dummy
  }

  auto macChallengeExample = []()
{
  uint8_t command[MAC_COUNT_LONG];
  uint8_t response[MAC_RSP_SIZE];

  const uint8_t challenge[MAC_CHALLENGE_SIZE] = {
    0x00, 0x11, 0x22, 0x33, 0x44, 0x55, 0x66, 0x77,
    0x88, 0x99, 0xAA, 0xBB, 0xCC, 0xDD, 0xEE, 0xFF,
    0x00, 0x11, 0x22, 0x33, 0x44, 0x55, 0x66, 0x77,
    0x88, 0x99, 0xAA, 0xBB, 0xCC, 0xDD, 0xEE, 0xFF
  };

  uint8_t ret_code = sha204dev.execute(SHA204_MAC, 0, 0, MAC_CHALLENGE_SIZE, 
    (uint8_t *) challenge, 0, NULL, 0, NULL, sizeof(command), &command[0], 
    sizeof(response), &response[0]);

  for (int i=0; i<SHA204_RSP_SIZE_MAX; i++)
  {
    Serial.print(response[i], HEX);
    Serial.print(' ');
  }
  Serial.println();
  
  return ret_code;
};

  //macChallengeExample();


  auto dump_configuration = []()
  {
    uint8_t readCommand[READ_COUNT];
    uint8_t readResponse[READ_4_RSP_SIZE];
  
    // list all configurations
    for(int i=0; i<= 0x15; i++)
    {
      uint8_t returnCode = sha204dev.read(readCommand, readResponse, SHA204_ZONE_CONFIG, i*4);
      printf("%02X ", readResponse[SHA204_BUFFER_POS_DATA], HEX);
      printf("%02X ", readResponse[SHA204_BUFFER_POS_DATA+1], HEX);
      printf("%02X ", readResponse[SHA204_BUFFER_POS_DATA+2], HEX);
      printf("%02X\n", readResponse[SHA204_BUFFER_POS_DATA+3], HEX);
    }
  };

  auto isLocked = []()
  {
    uint8_t tx_buffer[READ_COUNT];
    uint8_t rx_buffer[READ_4_RSP_SIZE];
    uint8_t ret_code;
    uint8_t lockConfig = 0;
    uint8_t lockValue = 0;
    
    // Read out lock config bits to determine if locking is possible
    ret_code = sha204dev.read(tx_buffer, rx_buffer, SHA204_ZONE_CONFIG, 0x15<<2);
    if (ret_code != SHA204_SUCCESS)
    {
      Serial.print(F("Failed to determine device lock status. Response: ")); Serial.println(ret_code, HEX);
      return ret_code;
    }
    else
    {
      lockConfig = rx_buffer[SHA204_BUFFER_POS_DATA+3];
      lockValue = rx_buffer[SHA204_BUFFER_POS_DATA+2];
    }

    return ret_code;
    
  };

  dump_configuration();
  isLocked();

  Scheduler.start(setup_status, loop_status);
  Scheduler.start(setup_i2c, loop_i2c);

}

void setup_status()
{
  
}

void loop_status()
{
  static bool togle = false;

  if(togle)
    digitalWrite(9,LOW);
  else
    digitalWrite(9,HIGH);

  togle = !togle;
  
  delay(100); 
}

void setup_i2c()
{
  // Initialise I2C communication as MASTER
  //Wire.begin();
  // Start I2C Transmission
  Wire.beginTransmission(Addr);
  // Continuous conversion mode, 8 SPS, 1PGA
  Wire.write(0x0C);
  // Stop I2C Transmission
  Wire.endTransmission();

}

void loop_i2c()
{
  
 unsigned int data[2];

  // Request 2 bytes of data
  Wire.requestFrom(Addr, 2);

  // Read 2 bytes of data
  // raw_adc msb, raw_adc lsb
  if (Wire.available() == 2)
  {
    data[0] = Wire.read();
    data[1] = Wire.read();
  }

  // Convert the data
  float raw_adc = (data[0] * 256.0) + data[1];
  if (raw_adc > 32767)
  {
    raw_adc -= 65536;
  }

  // Output data to serial monitor
  //Serial.print("Digital Value of Analog Input : ");
  //Serial.println(raw_adc);

  // 50v -- 65536 | x -- raw_adc -> normalization 1.056
  Serial.print("Voltage: ");
  Serial.println((((float)(raw_adc*50))/65536)*1.056*2);

  Wire.end();
  
  //delay(100);
  
  sensors.begin();

  Serial.print("Requesting temperatures...");
  sensors.requestTemperatures(); // Send the command to get temperatures
  Serial.println("DONE");
  Serial.print("Temperature for the device 1 (index 0) is: ");
  temp = sensors.getTempCByIndex(0);
  Serial.println();

  oneWire.skip();
  Wire.begin();

  delay(1000);

}

struct payload_t {                  // Structure of our payload
  unsigned long ms;
  unsigned long counter;
};
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

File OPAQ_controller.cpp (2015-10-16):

/*
 *  Opaq is an Open AQuarium Controller firmware. It has been developed for
 *  supporting several aquarium devices such as ligh dimmers, power management
 *  outlets, water sensors, and peristaltic pumps. The main purpose is to
 *  control fresh and salt water aquariums.
 *
 *    Copyright (c) 2015 Andre Pedro. All rights reserved.
 *
 *  This file is part of opaq firmware for aquarium controllers.
 *
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
 */

#include <pgmspace.h>
#include <FS.h>

#include "OPAQ_controller.h"
#include "Rf433ook.h"
#include "websites.h"

// non-class functions begin

static void ICACHE_FLASH_ATTR _deviceTaskLoop ( os_event_t* events )
{
  opaq_controller.run_task_ds3231();
}

static void ICACHE_FLASH_ATTR _10hzLoop ( os_event_t* events )
{
  opaq_controller.run_task_nrf24();
}

static void _devicesTask_timmingEvent()
{
  system_os_post ( deviceTaskPrio, 0, 0 );
}

static void _10hzLoop_timmingEvent()
{
  system_os_post ( _10hzLoopTaskPrio, 0, 0 );
}

// non-class functions end


/*=============================================================================
=                              Opaq public methods                            =
=============================================================================*/

OpenAq_Controller::OpenAq_Controller() :
  server ( ESP8266WebServer ( 80 ) ),
  timming_events ( Ticker() ),
  rtc ( RtcDS3231() ),
  radio ( RF24 ( 16, 15 ) ),
  html ( AcHtml() ),
  storage ( AcStorage() ),
  str ( String() )
{
  str.reserve ( 2048 );
}


void OpenAq_Controller::setup_controller()
{
  delay ( 2000 );

  // initialize seed for code generation
  randomSeed ( ESP.getCycleCount() );

  // setup serial for a baundrate of 115200
  Serial.begin ( 115200 );
  Serial.setDebugOutput ( true );

  if ( storage.getSignature() != SIG )
  {
    factory_defaults ( SIG ); // uncomment to set the factory defaults
    Serial.println ( "default settings applied." );
  }

  // Initialize file system.
  if (!SPIFFS.begin())
  {
    Serial.println("Failed to mount file system");
    ESP.restart();
  }

  // read openaq mode from eeprom
  bool mode = storage.getModeOperation() & 0b00000001;

  if ( mode )
  {
    const char* ssid = storage.getSSID();

    Serial.print ( "SSID: " );
    Serial.println ( ssid );

    // setup the access point
    WiFi.softAP ( ssid , storage.getPwd() ); // with password and fixed ssid
  }
  else
  {
    // or setup the station
    const char* ssid = storage.getClientSSID();
    const char* pwd = storage.getClientPwd();
    
    Serial.print ( "Connecting to " );
    Serial.println ( ssid );

    WiFi.begin ( ssid, pwd );

    int count_tries = 0;

    while ( WiFi.status() != WL_CONNECTED )
    {
      delay ( 500 );
      Serial.print ( "." );
      count_tries++;

      if (count_tries > 100)
      {
        Serial.println ( "returning to AP mode. Reboot." );
        storage.enableSoftAP();
        storage.save();
        ESP.restart();
      }
    }

    Serial.println ( "WiFi connected" );
    Serial.println ( "IP address: " );
    Serial.println ( WiFi.localIP() );
  }

  // setup webserver
  server.on ( "/"      , std::bind ( &OpenAq_Controller::handleRoot, this ) );
  server.on ( "/light" , std::bind ( &OpenAq_Controller::handleLight, this ) );
  server.on ( "/clock" , std::bind ( &OpenAq_Controller::handleClock, this ) );
  server.on ( "/power" , std::bind ( &OpenAq_Controller::handlePower, this ) );
  server.on ( "/advset", std::bind ( &OpenAq_Controller::handleAdvset, this ) );
  server.on ( "/global", std::bind ( &OpenAq_Controller::handleGlobal, this ) );

  // setup webfiles for webserver
  for ( int fl = 0; fl < N_FILES; fl++ )
  {
    server.on ( files[fl].filename, [ = ]()
    {
      server.sendHeader ( "Content-Length", String ( files[fl].len ) );
      server.send_P ( 200, files[fl].mime, ( PGM_P )files[fl].content,
                      files[fl].len );
    } );
  }

  server.onNotFound ( [ = ]()
  {
    server.send ( 404, "  text/plain", String ( "    " ) );
  } );

  // start server
  server.begin();

  // RF433 setup
  Rf433_transmitter.set_pin ( 2 );
  Rf433_transmitter.set_encoding ( Rf433_transmitter.CHANON_DIO_DEVICE );

  // RTC setup
  rtc.Begin();
  Wire.begin ( 4, 5 );

  // NRF24 setup and radio configuration
  radio.begin();
  radio.setChannel(1);
  radio.setDataRate(RF24_1MBPS);
  radio.setAutoAck(false);
  //radio.disableCRC();
  radio.openWritingPipe( 0x5544332211LL ); // set address for outcoming messages
  radio.openReadingPipe( 1, 0x5544332211LL ); // set address for incoming messages
  
  // manual test
  //uint8_t buf[5] = {0x11, 0x22, 0x33, 0x44, 0x55};
  //radio.write_register ( TX_ADDR, buf, 5 );
  //radio.write_register ( SETUP_AW, 0x3 );
  //radio.write_register ( EN_AA, 0x0 ); // mandatory - no ACK
  //radio.write_register ( EN_RXADDR, 0x0 );
  //radio.write_register ( SETUP_RETR, 0x0 );
  //radio.write_register ( RF_CH, 0x1 );
  //radio.write_register ( RF_SETUP, 0x7 );
  //radio.write_register ( CONFIG, 0xE ); // mandatory

  //radio.startListening();

  // for debug purposes of radio transceiver
  radio.printDetails();

  // registers deviceTask in the OS control structures
  system_os_task ( _deviceTaskLoop, deviceTaskPrio, deviceTaskQueue,
                   deviceTaskQueueLen );

  system_os_task ( _10hzLoop, _10hzLoopTaskPrio, _10hzLoopQueue,
                   _10hzLoopTaskQueueLen );

  // Attach deviceTask event trigger function for periodic releases
  timming_events.attach_ms ( 5000, _devicesTask_timmingEvent );

  t_evt.attach_ms ( 50, _10hzLoop_timmingEvent );
}

int count=0;
void OpenAq_Controller::run_controller()
{
  server.handleClient();

  if (count == 100000)
  {
    opaq_controller.run_task_rf433ook();
    count=0;
  }
  count++;

}

void OpenAq_Controller::updatePowerOutlets ( uint8_t pdeviceId )
{
  bool vector[36] = { 0 };
  // vector is organized as follows :
  // |-----------ID-----------||-GROUPFLAG-||-ON/OFF-||-GROUPID-||-DIMMER-|
  // 00111101111110001011111110    0           1         0000       0000
  // 00111101111110001011111110    0           1         0001       0000

  int j = 0;
  uint32_t code = storage.getPDeviceCode ( pdeviceId );

  while ( j < 26 && code )
  {
    vector[j++] = code & 1;
    code >>= 1;
  }

  // set group flag
  vector[26] = 0;

  // set state
  uint8_t state = storage.getPDeviceState ( pdeviceId );

  if ( state == OFF || state == UNBINDING )
  {
    vector[27] = 0;
  }
  else
  {
    vector[27] = 1;
  }

  for ( int i = 0; i < 36; i++ )
  {
    DEBUGV ( "%d,", vector[i] );
  }

  DEBUGV ( "\n" );
  // lets sent a test message
  //bool bvector[36] = {1,1,0,0,0,0,1,0,0,0,0,0,0,1,1,1,0,0,0,0,0,0,0,0,1,0, 0, vector[27], 0,0,0,0, 0,0,0,0}; // max message is 36bits

  for ( int i = 0; i < 3; i++ )
  {
    Rf433_transmitter.sendMessage ( vector );
    delayMicroseconds ( 8000 );
  }
}
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

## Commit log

2015-09-09 Web interface for power outlets has been added. Devices are now managed by tasks.
2015-10-07 OPAQ is now under evaluation for the next release v1.0.1 Support for dealing with several power outlets at the same time have been added.
2015-10-08 Power outlets are now visible in the light settings as piecewise functions.
2015-10-13 New firmware. Speedup of the webpage loading. Reboot and factory settings buttons have been inserted.
2015-10-14 Several features are corrected. They are - Client SSID and PWD size have been increased. - Speedup of the webpage loading. - Reboot and factory settings buttons have been inserted. - Power outlet iss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
    [OPAQ_controller.cpp]
2015-10-16 SPIFFS support is added. Issues of power outlet timings are corrected. Labels are assigned to each power socket.
2015-10-16 New release 1.0.2.
    Several issues have been corrected. They are
    - Webpage loading performs fast by calculating the content size before send it.
    - Client SSID and PWD length are increased.
    - Power outlet GUI related issues are solved.
    - Power outlet timings issues are solved.
    New features:
    - SPIFFS support is added.
    - Labels are assigned to each power socket.
    - Reboot and factory settings buttons are inserted.
    [OPAQ_controller.cpp]
2015-10-22 Power outlet issues were solved.
    [Opaq_c1.cpp]
2015-10-26 Release 1.0.3. This release contains tweaks for timings of the rf switches device driver. Rf switches can now initialize without randomly binding when opaq c1 is running. Several graphical user inter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
    [Opaq_c1.cpp, Rf433ook.cpp, opaq.ino]
2015-11-04 Opaq C1 board v1.0 has released. Source-files are available over the CC-SA license.
    [opac_c1.GBL, opac_c1.GBO, opac_c1.GBP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]
2015-11-04 Revision 1 of opac.c1 board.
    [opac_c1.brd, opac_c1.sch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]
2015-11-05 Opaq.c1 revision 2.
    [opac_c1.brd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]
2015-11-11 Release 1.0.3 rev.1 - Readme has been changed. - Small corrections on UI. - Scripts for graphics have been modified to support mobile devices.
    [Opaq_c1.cpp]
2015-11-12 Image has been coupled to readme.
2015-11-18 Opac n1 hardware released.
    [opaq_n1.brd, opaq_n1.sch]
2015-11-19 Opaq n1 board revision 1.
    [opaq_n1.brd, opaq_n1.sch]
2015-11-22 Opaq C1 hardware revision 3.
    [opac_c1.GBL, opac_c1.GBO, opac_c1.GBP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]
2015-11-24 Opaq n1 hardware revision 2.
    [opaq_n1.brd, opaq_n1.sch]
2016-05-10 Opaq c1 version 1.1 has been released.
    [opac_c1.GBL, opac_c1.GBO, opac_c1.GBP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]
2016-05-10 Opaq n1 version 2.1 has been released.
    [board.skp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]
2016-07-02 Opaq c1 supports iaqua graphical interface.
    The touch screen and the 320x240 tft is now supported.
    Added features:
    - file storage manager using JSON for opaq settings.
    - touch screen calibration.
    - coprocessor program to interact with real-time clock, cypher chip (SHA204), and expansion of the GPIO.
    - ISP programmer for AVR coprocessor.
    [opaq_n2.brd, opaq_n2.sch]
2016-07-02 Several issues of the Opaq c1 hardware have been fixed.
    [opac_c1.GBL, opac_c1.GBO, opac_c1.GBP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]
2016-07-04 Opaq c1 hardware has been updated.
    - pull-up resistor have been added to RF433 signal.
    [opac_c1.brd, opac_c1.sch]
2016-08-13 Added the new fixes for opaq c1 hardware.
    [opac_c1.brd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]
2016-08-13 Added support for using hash maps for RF433 power outlets. Minor fixes for web ui, opaq c1 configuration files, and co-processor interface have also been done.
    [Opaq_c1.cpp, Opaq_com.cpp, Opaq_storage.cpp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]
2016-08-13 Added Arduinojson repository.
2016-08-23 Pre release of the opaq c1 version 1.0.5
    - loading screen for the opaq iaqua
    - power devices plugin
    - light dimmer devices plugin
    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
2016-08-23 Updated version of the opaq c1 hardware.
    [opac_c1.brd, opac_c1.sch]
2016-09-22 Release of version 1.0.6 Several fixes: - Fixed the webpage loading speed and some timeouts. - Added the cli interface with support for file uploading. - Added support for using standard unix command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
    [Opaq_c1.cpp, Opaq_com.cpp, Opaq_command.cpp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]
2016-10-25 Updated the Opaq n1 firmware to read the external temperature and the input voltage. Added the support for the external flash. Renamed the folder of the Opaq n1 hardware.
    [board.skp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]
2016-10-31 Split hardware files from source code.
    [board.skp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]
2016-11-03 Updated opaq n1 firmware to communicate with a mesh of rf24 nodes. - non-volatile memory tested - atsha204 cypher chip tested - temperature sensor ds18b20 tested - voltage sensor tested RF24 ACK bit 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
    [n1.ino]
2016-11-03 Fixed pinMode for SPI CS pins.
    [coprocessor.ino]
2016-11-15 Added support for connecting opaq c1 to thingspeak and share sensor data from opaq nodes. Several fixes have been done for opaq c1 firmware including stopping the 433mhz transmitter when idle, and op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
    [Opaq_c1.cpp, Opaq_com.cpp, Opaq_command.cpp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]
2020-04-06 Fix zmodem. Update scheduler to master. Update esp8266 core.
    [Opaq_command.cpp, Opaq_iaqua.cpp]
2020-04-06 Fix small issues. Set version 1.0.7.
    [Opaq_c1.cpp, Opaq_command.cpp]
2020-04-06 Fix code style standards.
    [Opaq_c1.cpp, Opaq_com.cpp, Opaq_command.cpp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]
2020-04-08 Fix task layout and multithread lock and unlock.
    [Opaq_c1.cpp, Opaq_com.cpp, Opaq_command.cpp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]
2020-04-13 Fix ArduinoJson to version 6. Fix ESPAsyncWebServer to redefinitions of LinkedList using a different namespace.
    [Opaq_c1.cpp, Opaq_command.cpp, Opaq_iaqua.cpp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]

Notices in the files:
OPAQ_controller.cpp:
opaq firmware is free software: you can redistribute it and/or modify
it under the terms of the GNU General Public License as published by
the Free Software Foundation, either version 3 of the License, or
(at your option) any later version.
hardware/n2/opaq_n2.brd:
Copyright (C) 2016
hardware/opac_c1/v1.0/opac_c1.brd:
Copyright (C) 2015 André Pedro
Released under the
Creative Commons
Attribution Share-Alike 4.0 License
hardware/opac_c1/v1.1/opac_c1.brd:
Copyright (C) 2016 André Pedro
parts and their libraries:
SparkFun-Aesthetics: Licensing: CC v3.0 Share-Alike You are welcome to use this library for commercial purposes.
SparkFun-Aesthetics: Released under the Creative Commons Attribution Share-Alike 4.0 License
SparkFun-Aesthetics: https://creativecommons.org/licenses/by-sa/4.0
